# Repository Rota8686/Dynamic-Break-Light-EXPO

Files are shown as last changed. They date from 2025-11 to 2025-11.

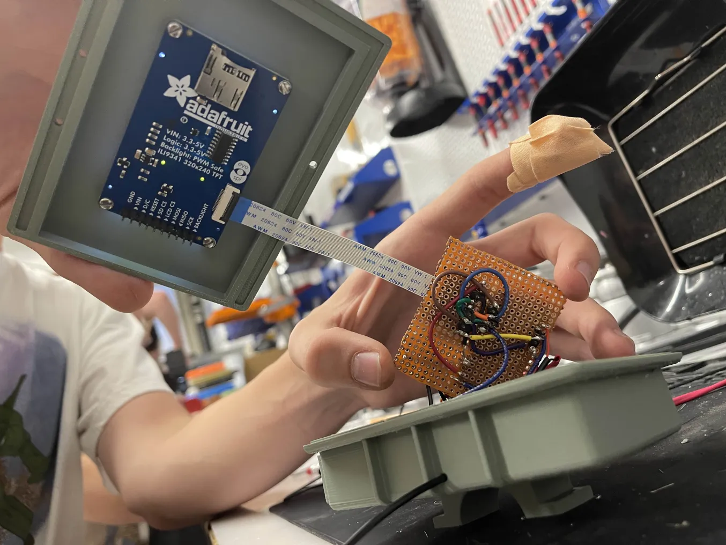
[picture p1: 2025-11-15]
Main Project/Soldering and Assembly/Display Soldering Bottom.webp

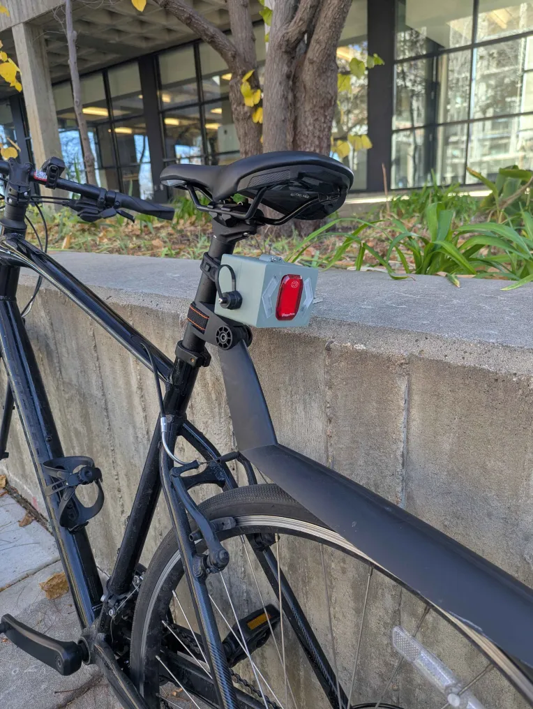
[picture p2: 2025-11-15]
Main Project/Soldering and Assembly/Mounted LED Module Picture.webp

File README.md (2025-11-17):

# Dynamic-Break-Light-EXPO-Repository

This repository holds the final versions of all the files created for the expo prize winning Dynamic Brake Light.

Expo Winning Photo Cropped

Left to Right: Jacob Nguyen, Roman Tagliola, Rowan McCune, Mitchell Vallis, and Liza Gunther (TA)

note: Mitchell Vallis is in Liza Gunther's hands because he had a wedding obligation the day of expo.

# Folder Structure

The "Main Project" folder contains final versions of all the files create for the Dynamic Brake Light, organized into CAD, code, soldering and assembly, presentation materials and technical documents, and expo photos.

The "Team Members" folder holds folders containing each team member's contributions to the Dynamic Brake Light.  These personal folders are organized in a similar manner to the "Main Project" folder, minus an "expo photos" folder.

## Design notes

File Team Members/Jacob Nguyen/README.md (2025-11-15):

## Jacob Nguyen

Jacob Nguyen was a core part of the Dynamic Brake Light team.  Jacob put substantial time and effort into designing the housing for the LED module, developing his soldering skills and diligently preparing useful technical documents and presentation materials.  

Jacob's most significant contribution to the Dynamic Brake Light was his LED module housing.  Going into the project with little CAD experience, Jacob developed a great command over the SolidWorks tools, using them to design a well-thought-out housing.  Jacob balanced visual appeal with clearly identifiable brake and turn signal lights.  To this end, Jacob worked closely with Mitchell Vallis and Rowan McCune to add turn signal cutouts and integrate parts from a commercially available bike light into the LED module housing.

With regard to the implementation of turn signals, Jacob design a geometry for snuggly nesting a single LED bulb flush in the housing.  Jacob developed this geometry through a careful process of trial and error, ultimately resulting in turn signal LED arrays, paired with sanded acrylic cutouts, visible in daylight from any practical angle.  Jacob learned how to operate the laser cutters in the ITLL, where he designed and cut acrylic that held a snug tolerance with the cutouts on the housing.  

During the assembly of the demo version of the Dynamic Brake Light, Jacob dealt with the difficult task of soldering within a compact casing.  From this experience, Jacob greatly improved his soldering technique, as evident by this clean cable management and solid solder joints.  Jacob provided a necessary hand during final assembly and testing, ensuring that all systems functioned properly the night before expo.

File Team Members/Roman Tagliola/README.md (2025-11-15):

## Roman Tagliola

Roman Tagliola was a critical member of the Dynamic Brake Light team.  Roman's most significant contributions to the project include designing the display module, helping the other team members with design subtleties, ensuring timely procurement of electrical components and hardware, and preparing high quality technical documents and presentation materials.  

 Roman demonstrated his command of Onshape's CAD tools in the design of the display module housing, as shown in mounting of the LCD board to the upper clamshell, the fitment and spacing of the display inputs and access points, and the mating of the upper and lower clamshells.  Roman worked with Rowan McCune to integrate the Hall-Effect sensor system with the display module using a cutout in the display housing to connect the sensor to the micro controller using a QWIIC cable setup.

In addition to designing the display module housing, Roman developed the program for the display's micro controller.  The display's program features three user inputs in the form of a reset button, debug/normal UI switch, and a normal/sleep switch.  Roman was responsible for researching and implementing wireless communication between the display and LED modules, which uses an ESP-NOW Wi-Fi channel to maintain two-way transmission between the modules.

Roman laid out and built the circuit boards within the display housing, with soldering assistance from Mitchell Vallis.  Wiring the connections between the micro controller and the display's wire-to-flex board was particularly challenging given eight wires needed soldering in close proximity.  The wiring for the turn signals, switches and button added further complexity to the main board layout.  

By acting as a sounding board for the rest of the team, Roman contributed to the design and exicution of the rest of the project.  Roman encouraged the implementation of the project's reach goal, the addition of turn signals, by providing a picture of how finished turn signals could look and by being proactive in the addition of turn signal functionality to the display module.  Roman also helped Mitchell research reading filter techniques.  

In order to ensure timely procurement of electrical components and hardware, Roman made multiple trips to pick up part orders from SparkFun and hardware from McGuckin's Hardware, local stores based on Niwot, CO and Boulder, CO respectively.

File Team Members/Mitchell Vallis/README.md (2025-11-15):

# Mitchell Vallis

Mitchell Vallis was a critical part of the Dynamic Brake Light team.  Mitchell's primary contributions include envisioning the idea of a dynamic brake light, coding the LED module's micro controller, designing and assembling the LED module's circuit board, and creating high quality technical documents and presentation materials.  Mitchell also helped with designing a compact housing for the LED module and integrating the LED and display systems

During the development of the Dynamic Brake Light, Mitchell was faced with faulty electrical components, intricate coding challenges, and demanding spatial constraints within the LED module housing.  While successfully solving these problems, Mitchell learned proper soldering techniques and developed code to filter and interpret accelerometer readings with the purpose of dynamically controlling LED arrays.

Mitchell's chief accomplishment was writing the code for the accelerometer circuit.  This code turned raw accelerometer voltage readings into dynamically LED controlled arrays using medium pass filters and PWM gradients.

Mitchell's proactive approach to assisting Jacob Nguyen with designing of the LED module housing involved the disassembly of commercially available bike lights and USB cables.  From these items, Mitchell gathered a central LED array and front and rear housing elements seen on the LED module in addition to flexible USB plugs.  Mitchell's instinct to study and integrate what already works directly led to the improvement of the LED housing.  In less words, in the process of helping Jacob, Mitchell constructed a LED module housing that maintained a low profile while containing a circuit board and three separate LED arrays.  

Mitchell worked with Roman Tagliola to establish wireless communication between the LED and display modules using a two-way ESP-NOW Wi-Fi channel.  This wireless communication transmitted accelerometer readings from the LED module to the display and turn signal inputs from the display to the LED module.  Mitchell was committed to the final assembly of the project, designing the internal layout for the LED module and helping Roman with soldering the display module.

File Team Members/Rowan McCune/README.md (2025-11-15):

## Rowan McCune

Rowan McCune was an integral part of the Dynamic Brake Light team.  Rowan made valuable contributions to the project through designing the Hall-Effect sensor system, becoming proficient in his soldering technique, and preparing intuitive presentation materials.  

Rowan's more impressive contribution to the Dynamic Brake Light was his designing and testing of the Hall-Effect sensor system.  The Hall-Effect sensor reads magnetic fields to track wheel rotations, which are in turn used to calculate distance traveled and current velocity.  Rowan exhibited his CAD skills with a robust pair of housing for the Hall-Effect sensor and the magnet caddy.  Rowan designed an effecting script to read the Hall-Effect sensor, featuring tailored baseline adjustments and optimized operating frequencies.  Rowan used the sensor reading script to help Roman Tagliola integrate the sensor readings into the display module's informative UI.  

Rowan demonstrated his soldering technique during final assembly, where he soldered the turn signal LED arrays onto dual-sided copper plated boards, ensuring minimal wiring in the LED module housing and consistent, robust electrical connections.  

Rowan was tasked with making custom acrylic cutouts to fit the turn signals. To accomplish this task, Rowan determined the best combination for our scenario required the acrylic to be sanded and the tops of the LEDs to be grinded flat.  These two design elements together created effective turn signals that are bright and resemble chevrons.

The logo present on PDR and CDR presentations in addition to the display and LED modules is Rowan's design.  The three circles filled with varying shades of red represent the dynamically controlled LED arrays.  The geometric design is reminiscent of logos such as the NASA insignia and the Star Fleet delta emblem.

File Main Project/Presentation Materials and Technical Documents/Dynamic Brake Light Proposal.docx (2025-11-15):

Dynamic Brake Light

Team Light Brakers

Team 21

Lecture WF 3:35p

Rowan McCune, Jacob Nguyen, Roman Tagliola, Mitchell Vallis

“Emails”

Abstract:

Our project is a dynamic break light that increases in brightness the more you are applying the break. This would be most beneficial in cars, to indicate to the person behind the vehicle how much the person in pressing on the breaks. This could lead to decreased car accidents as people would now be aware when the driver ahead of them is slamming on the breaks. We will be implementing this idea and design on a bicycle.

Project Scope:

Plan A:

Our dynamic break light will increase brightness the harder the user is pressing on the brakes. A lollipop shaped device will be attached to the exterior of the handlebars. The stick portion of the lollipop will face forward and will be a channel with a spring inside. The brake handle will fit into the channel. As the break is pulled, the spring will compress, pushing down on a pressure plate at the base of the spring. The more force applied to the pressure plate, the brighter the break light will light up.

Our goal is to create an original, functioning device. The design of the project will allow us to gain experience in coding, 3D printing, design, installation, and troubleshooting. Project success means the light increases in brightness as we increase pressure on the brake handle.

The project will be split into three sections. Coding, 3D design and printing, and installation and troubleshooting. We will create and code the device ourselves. We will use the laser scanner to scan the handlebars of the bike and use those scans to create the attachment for the handlebars. We will buy the spring, wiring, an Arduino to program, and an LED for the brake light. Other miscellaneous pieces might be required as the project gets underway. The 3D printers and laser scanner within the ITLL will be useful and necessary for this project.

Plan B:

Due to the complexity of Plan A, we have come up with a Plan B that uses an accelerometer. We will use an accelerometer to measure acceleration. If there is negative acceleration, the brake light will light up. The greater the deceleration, the greater the brake light lights up.

Specifications:

Electrical:

Component | Minimum Performance | Maximum Performance | Advertised Performance
Arduino | 3 Months | 5 Years | 2-10 years
Batteries | 20 hours | 200 hours | 120 hours
Light | 5,000 hours | 50,000 hours | 25,000 hours
Pressure Sensor | 200 Hours | 300 Hours | NA
Accelerometer | 200 Hours | 500 Hours

Mechanical:

Component | Minimum Performance | Maximum Performance | Advertised Performance
Wiring | 1 Year | 5 Years | 5 Years
Handle Bar Attachment | 6 months | 2 Years
Spring | 1 Year | 3 Years
Mounting Brackets | 2 Years | 4 Years

Design Elements:

Mechanical:

Electrical:

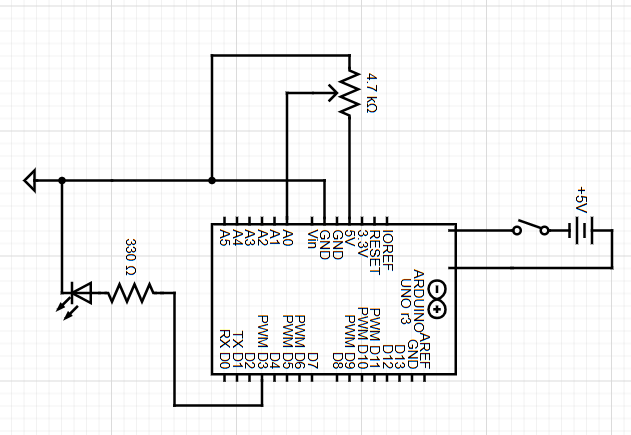
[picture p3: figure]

Bill of Materials:

Item: | Cost ($):
Arduino | $30
Filament for 3D printing | $10
LED | $10
Spring | $3
Wiring | $3
Batteries | $8
Battery Case | $5
On/off Switch | $3
Casing for Arduino | $25
Pressure Sensor | $13
Total: | $110

Risk Mitigation:

The biggest concern is the structural integrity of the Arduino, which we will program to control the LED. Exposure to the elements and vibrations from riding the bike could significantly shorten the life of the Arduino. The mitigate this, we will explore a shock and weather resistant casing.

Timeline:

9/30/25: All parts that need to be ordered are ordered

10/10/25: Designs for 3D printing finalized

10/17/25: Coding Finished

10/31/25: Troubleshooting and testing completed

11/9/25: Finished and installed on bike

Tools:

We will use 3D printers and laser scanners.

Conclusion:

Our plan is attempt Plan A, but due to the complexity and skill restraints, we will quickly shift to Plan B to make sure we have a fully functioning product by the date of the EXPO.

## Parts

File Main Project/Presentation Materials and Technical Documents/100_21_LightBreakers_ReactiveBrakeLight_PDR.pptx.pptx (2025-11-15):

## Light-Braker

Where Safety and Innovation Meet

## Presentation Outline

Idea

Concept

Problem

Timeline

Risk Mitigation

Testing

Summary

Bill of Materials

## Problem

- Most bikes don’t have a brake light to indicate that they are braking
- Congested bike lanes can reduce the rider’s reaction time leading to crashes

Solution

Create a brake light that lets trailing riders know you are braking and how fast

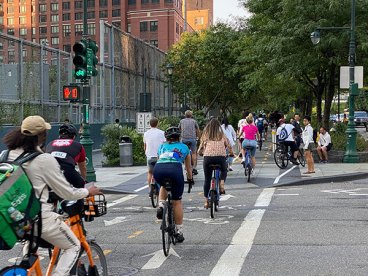
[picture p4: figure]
The BroadsheetDAILY - 10/11/22 - Street Wise - The Broadsheet

## Introducing the Dynamic Brake Light

- Increases in brightness the quicker you are slowing down
- Uses an accelerometer to take acceleration inputs
- As negative acceleration increases, power output to the brake light increases
- Added LCD display and distance tracking

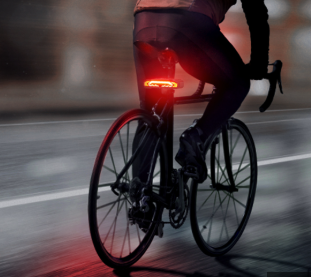
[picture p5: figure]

## Introducing the Dynamic Break Light

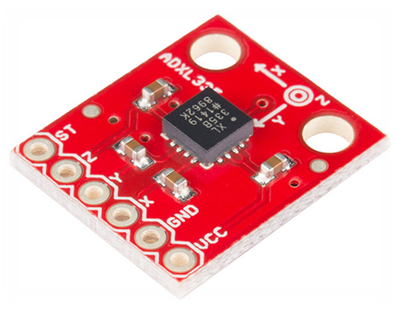
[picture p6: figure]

Accelerometer ADXL335 (https://www.digikey.com/en/htmldatasheets/production/466599/0/0/1/adxl335)

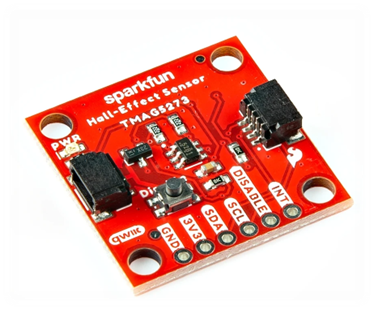
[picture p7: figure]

Hall-Effect Sensor (https://docs.sparkfun.com/SparkFun_Qwiic_Hall_Effect_Sensor_TMAG5273/assets/component_documentation/tmag5273.pdf)

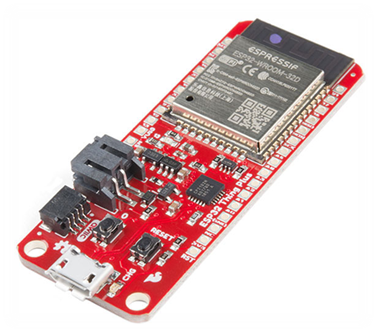
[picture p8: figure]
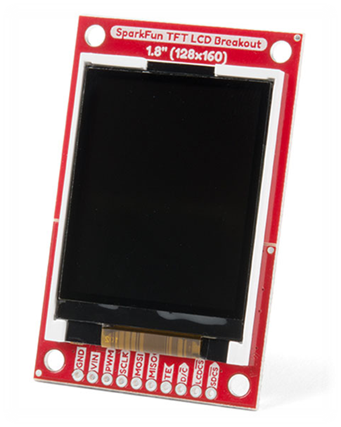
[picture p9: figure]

Thing Plus ESP32 (https://cdn.sparkfun.com/assets/4/3/1/7/6/esp32-wroom-32e_esp32-wroom-32ue_datasheet_en_v1-6.pdf)

TFT LCD Breakout (https://cdn.sparkfun.com/assets/9/0/4/1/e/KWH018ST14-F01_B_20181212.pdf)

## Electronics

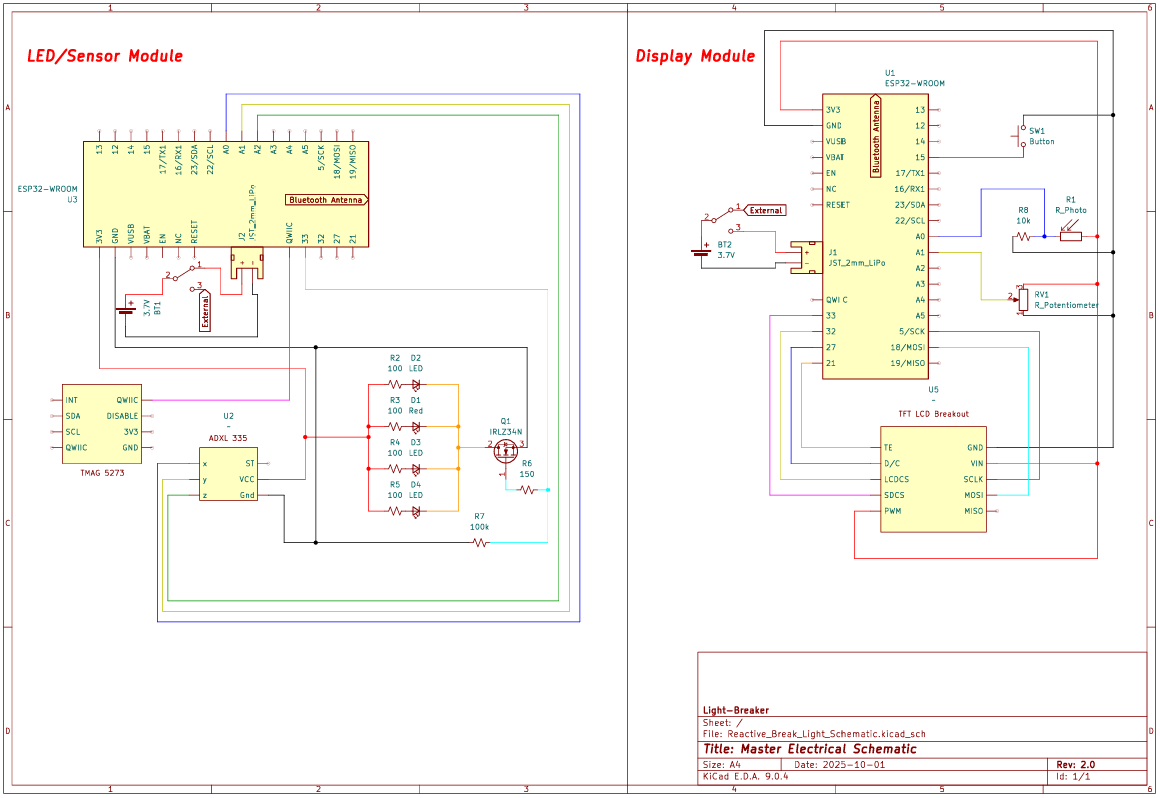
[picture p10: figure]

Why the ESP32 platform over the UNO?
- Size
- Processing Power
- Bluetooth and Wi-fi Integration
TFT LCD Breakout
- similar to the TI-84 PLUS CE display
- customizable interface
- SparkFun HyperDisplay library
Sensors provide analog readings, creating room for fine tuning.

## Code

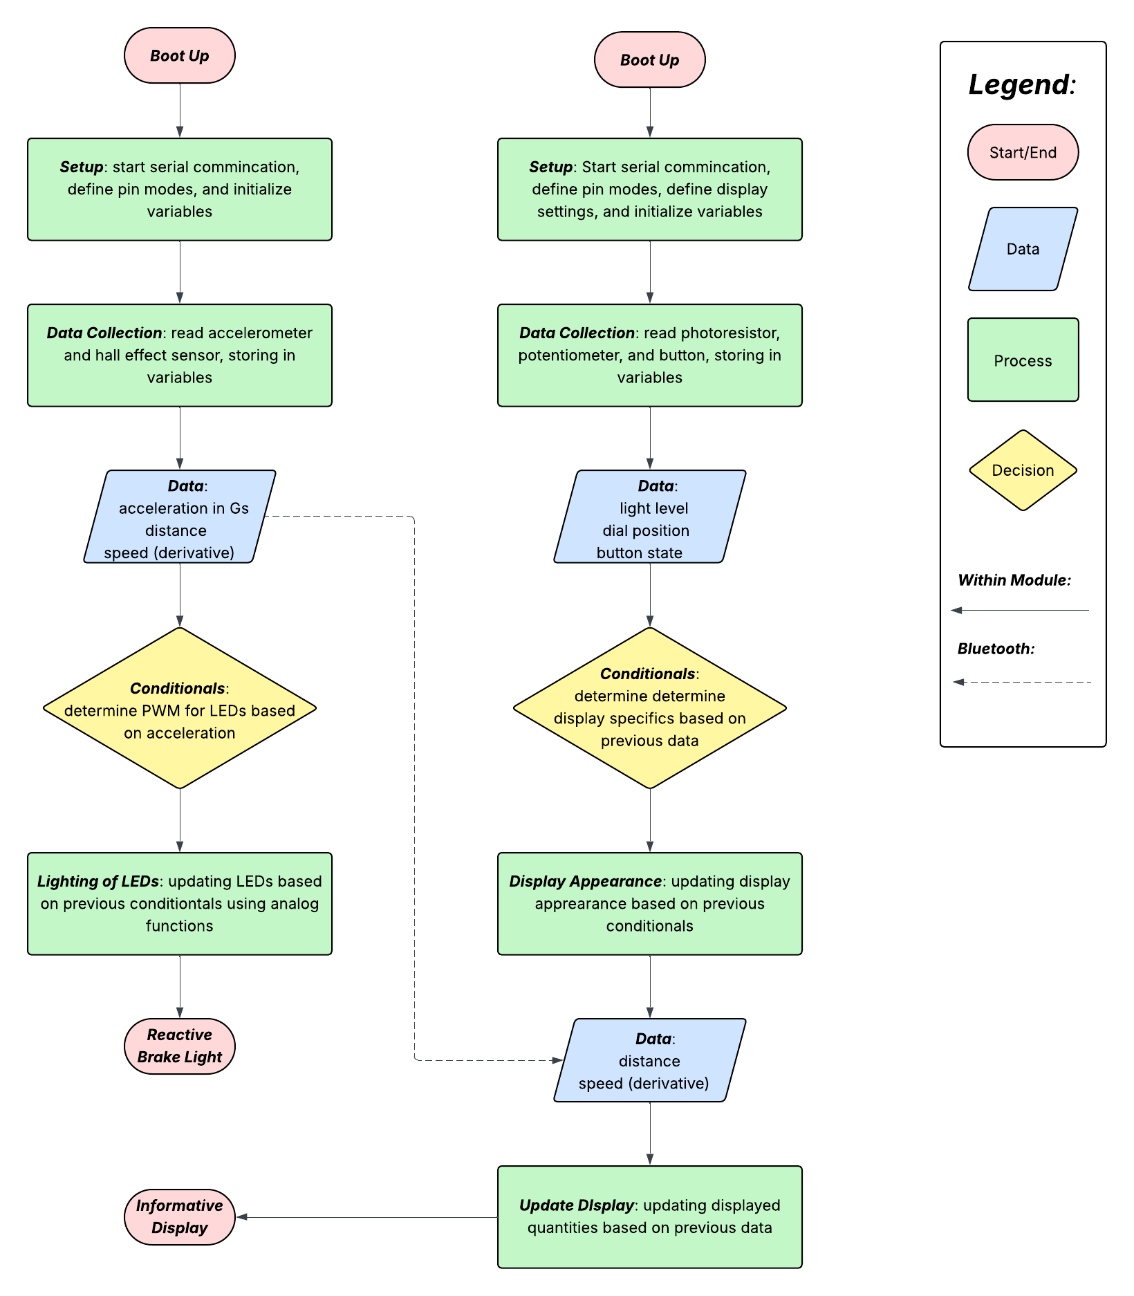
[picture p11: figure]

Arduino IDE
- easy to learn
- good user interface
- variety of documented libraries
  - Espressif esp32 library
  - SparkFun HyperDisplay library
  - ArduinoBLE library

Issues:
- esp32 specific analog functions
  - ledcWrite() alternative to analogWrite()
- 3.x.x verions of Espressif esp32 library broke the defining of ledc functions

## Electrical Enclosures


Software:
- Onshape (Cloud)
- PrusaSlicer

3D Printing:
- Prototyping: PLA
- Expo: Nylon Filament


## Timeline


Responsibilities:
- each teammate responsible for one area of the project
  - Mitchell: accelerometer
  - Jacob: LED array
  - Rowan: tachometer
  - Roman: LCD display

Jira:
- used to keep track of tasks, expenses, and deadlines
- Gantt Chart

## Testing Plan

Integration and Design:
- be resourceful.
- use amenities provided to us
- Craft a brand through seamless design. This is an expo!

Think Traffic - Philly Ad Club

Hardware:
- Ensuring that microcontrollers integrate well with our system
- LCD Screen
- Accelerometer
- Hall Effect Sensor
- Bluetooth Communication
- Batteries
- Test components on a breadboard. Spend time doing the MATH!

Solderless Breadboard 400 pins

Software:
- capable of supporting the hardware
  - ensuring everyone is on the same page
  - testing code before soldering

Free download | HD PNG arduino logo PNG transparent with Clear Background ID 222719 | TOPpng

## Risk Mitigation

Potential Risk | Our Plan
Not having enough power | To use an external supply that goes into the Arduino Board
Wires and connection coming loose due to bumps and shaking of the bicycle | Create absorbent casings that minimize the bumps, maintaining a strong connection and solder our parts.
Errors in coding when it comes to the luminosity of the lights, LCD Display, Accelerometer, and Hall-Effect Sensor | Preprogram all our components on a breadboard before attaching it to the bike, and using trial and error to resolve any errors

## Bill of Materials

Item Name | Price (USD) | Where? | Importance
SparkFun Triple Axis Accelerometer Breakout | 19.50 | Amazon | Measures our acceleration, allowing us to know when we are slowing down.
SparkFun Linear 3D Hall-Effect Sensor | 7.11 | Amazon | Magnetic field sensor to determine the distance travelled on the bike
LED – Super Bright Red (25 Pack) | 4.75 | SparkFun Electronics | Makes up or brake light on the back of the bike
SparkFun Qwiic Cable Kit | 12.95 | SparkFun Electronics | Allows us to wire things faster with less error
SparkFun Capacitor Kit | 11.50 | SparkFun Electronics | Allows us to more precisely control the thresholds
SparkFun TFT LCD Breakout – 1.8" (128x160) | 34.95 | SparkFun Electronics | This is our digital display for our speed, distance, etc.
2x SparkFun Thing Plus – ESP32 WROOM (Micro-B) | 24.95 per 49.90 total | SparkFun Electronics | These are the core of our circuit and project

## Summary

- We've identified an issue and have developed a solution
- Our dynamic brake light is intended to reduce bike accidents
- Through our planned testing and navigating risks our device will be optimized
Questions?

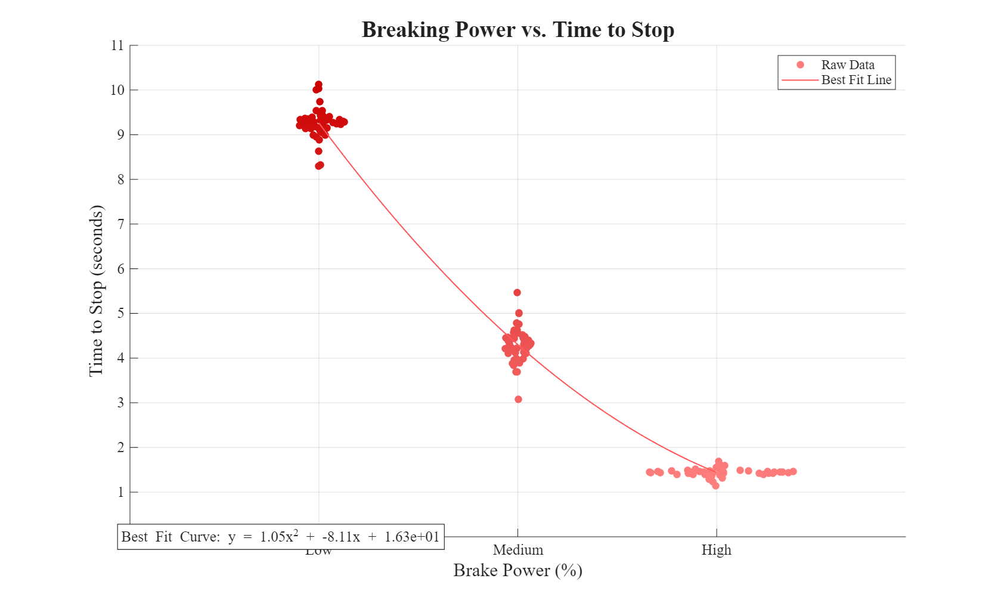
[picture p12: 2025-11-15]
Main Project/Presentation Materials and Technical Documents/MATLAB Graphs/bp_vs_tts.png

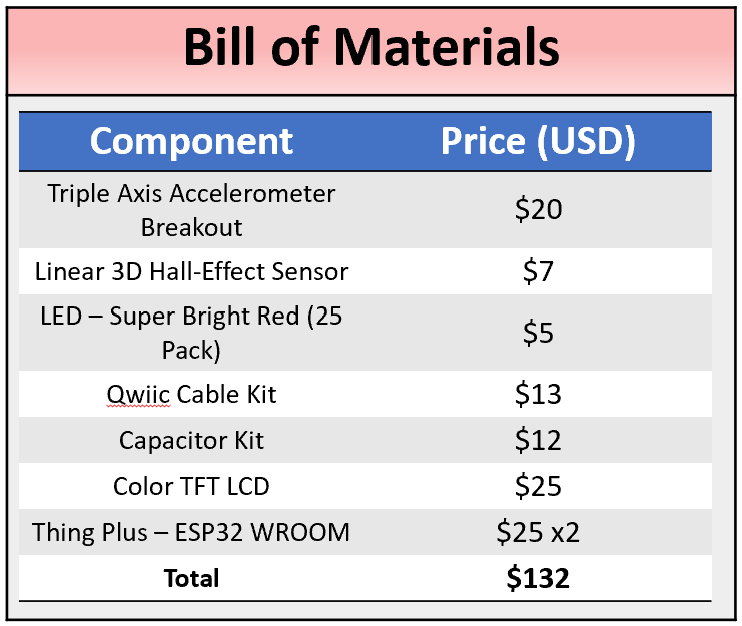
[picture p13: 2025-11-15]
Main Project/Presentation Materials and Technical Documents/Bill of Materials.png

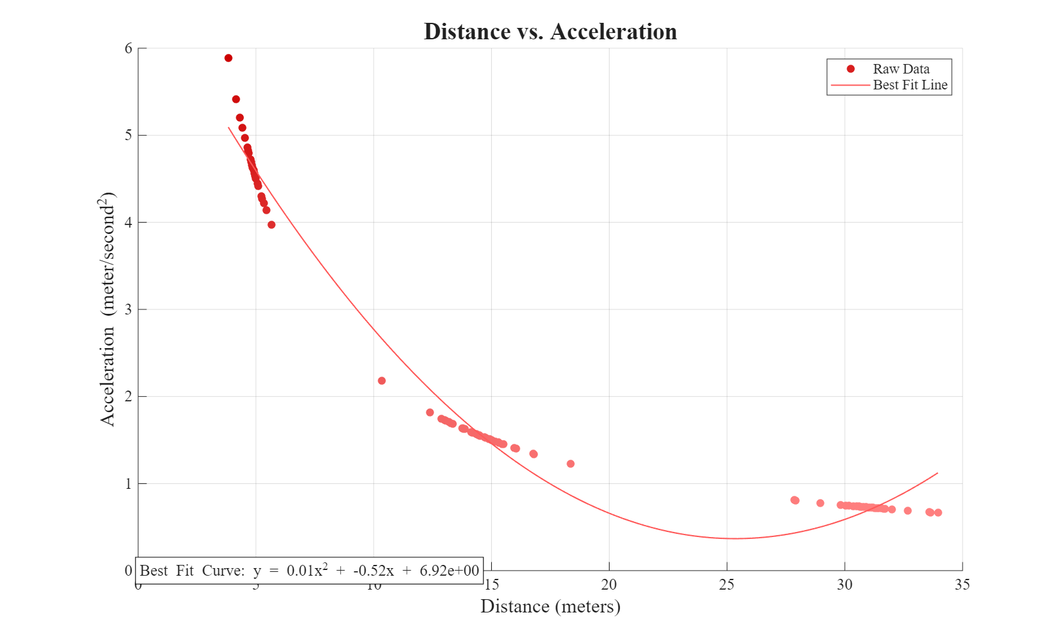
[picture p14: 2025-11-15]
Main Project/Presentation Materials and Technical Documents/MATLAB Graphs/a_vs_d.png

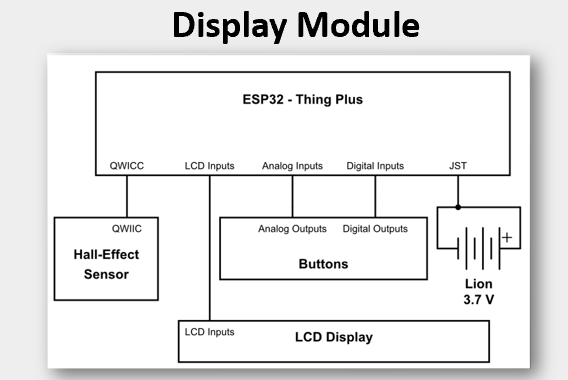
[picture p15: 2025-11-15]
Main Project/Presentation Materials and Technical Documents/Final Display Block Diagram.png

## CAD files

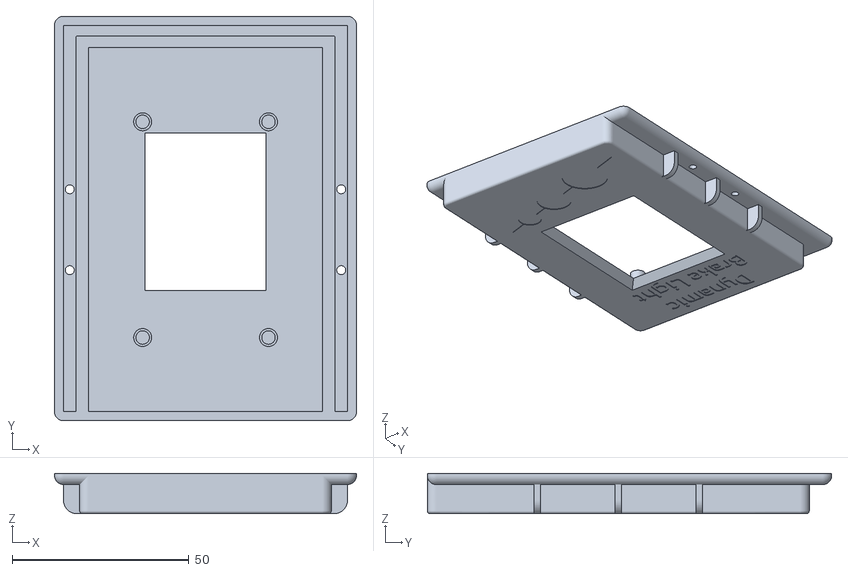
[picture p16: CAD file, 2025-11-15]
Main Project/CAD/Display Upper Clamshell V3.2.stl
85.3 x 114.3 x 11.4

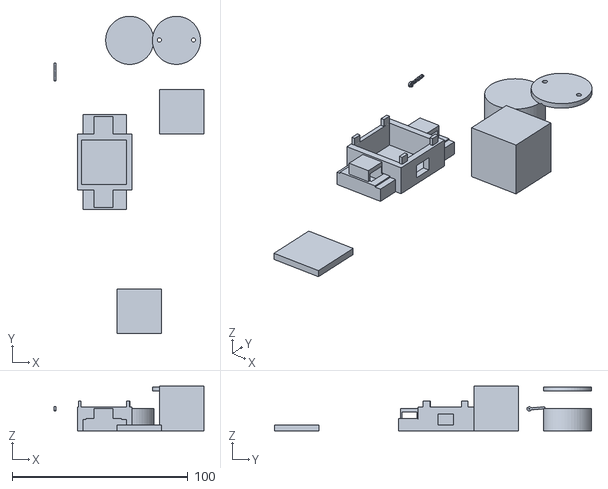
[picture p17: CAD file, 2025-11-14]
Team Members/Rowan McCune/CAD/Hall-Effect Sensor System CAD.stl
85.3 x 180.6 x 25.4

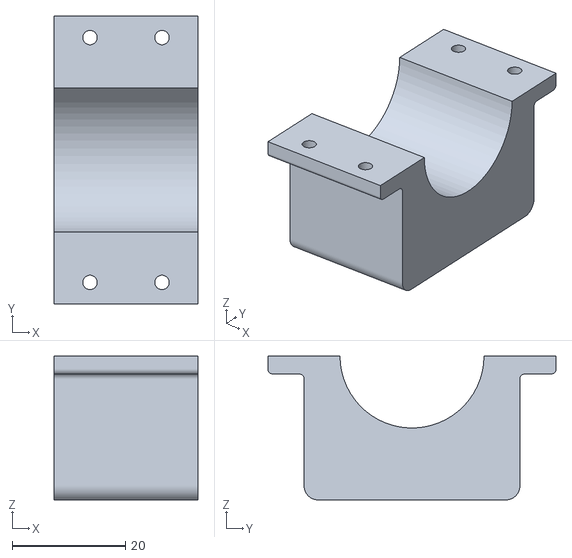
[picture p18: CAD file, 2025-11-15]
Main Project/CAD/Exterior Clamp V3.stl
25.4 x 50.8 x 25.4

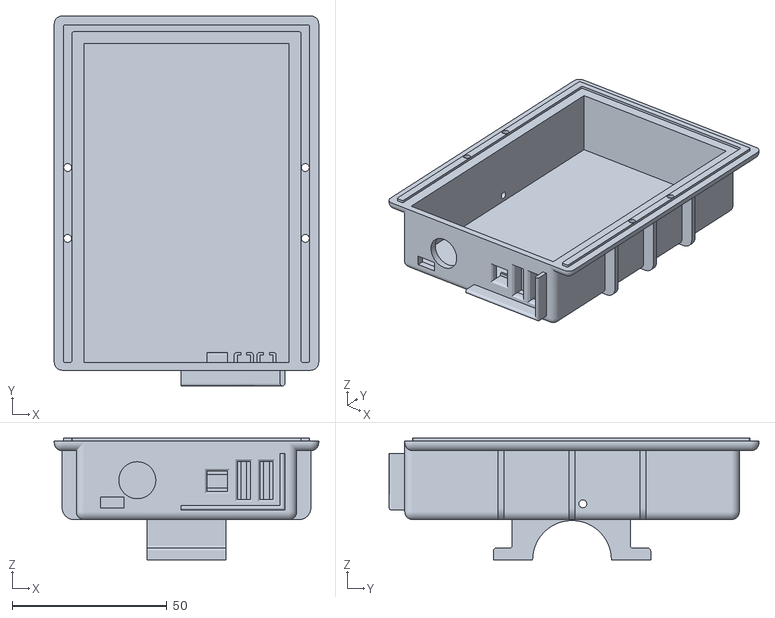
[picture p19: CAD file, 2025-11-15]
Main Project/CAD/Display Lower Clamshell V3.1.stl
85.3 x 119.4 x 39.3

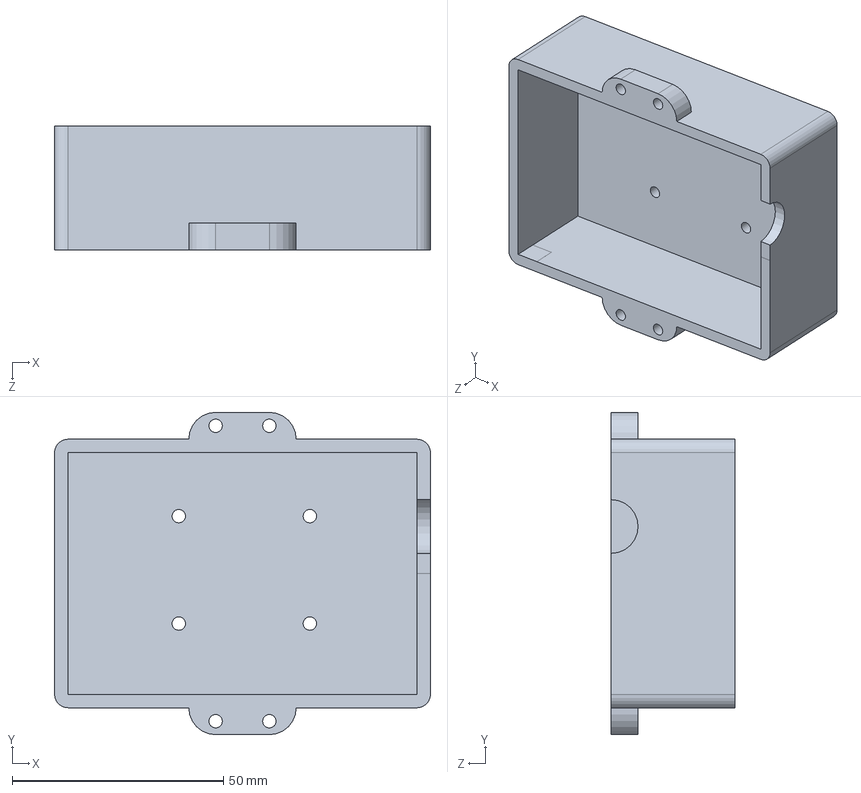
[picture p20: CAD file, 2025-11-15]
Main Project/CAD/Back Casing With Signals 2.SLDPRT
88.9 x 76.2 x 29.2 mm

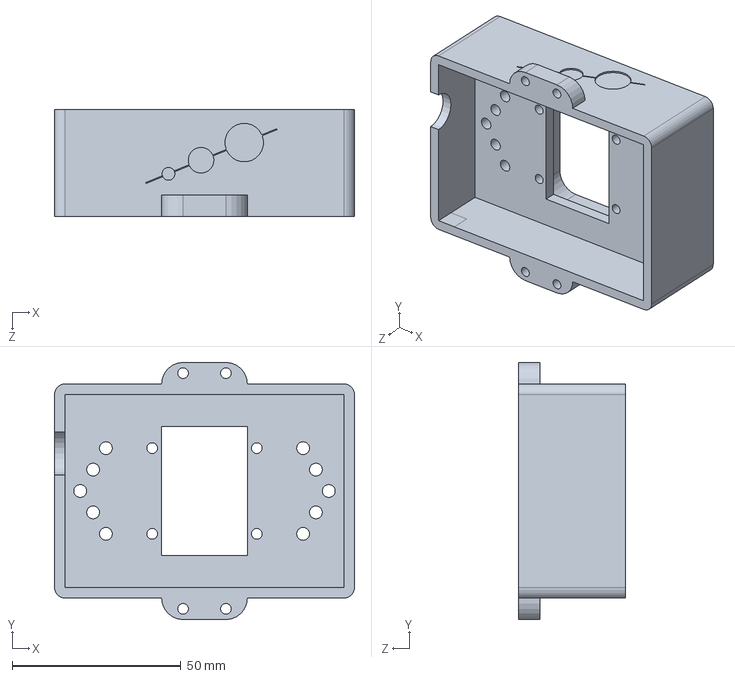
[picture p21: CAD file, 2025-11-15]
Main Project/CAD/Front Casing With Signals 5.SLDPRT
88.9 x 76.2 x 31.8 mm

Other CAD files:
Main Project/CAD/LED Glass Cut Out Shape.SLDPRT
Main Project/CAD/Back Casing With Signals 2.STL
Main Project/CAD/Front Casing With Signals 5.STL
Main Project/CAD/LED Glass Cut Out Shape.DXF

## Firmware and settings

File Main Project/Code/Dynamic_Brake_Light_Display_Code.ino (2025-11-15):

#include <TFT_eSPI.h>
#include <esp_now.h>
#include <WiFi.h>
#include <Wire.h>
#include <SparkFun_TMAG5273_Arduino_Library.h>

//I2C configuration
#define SDA_PIN 23
#define SCL_PIN 22

//control inputs 
#define POWER_SWITCH_PIN 32
#define MODE_SWITCH_PIN 4
#define RESET_BUTTON_PIN 0
#define SIGNAL_A_PIN 27
#define SIGNAL_B_PIN 14

//Hall-Effect sensor calibration
float Z_baseline = -0.68;
float Z_high = 1.0;
float Z_low = 0.3;

//wheel configuration
#define WHEEL_DIAMETER_CM 66.0
#define WHEEL_CIRCUMFERENCE_CM (WHEEL_DIAMETER_CM * 3.14159)
#define WHEEL_CIRCUMFERENCE_M (WHEEL_CIRCUMFERENCE_CM / 100.0)
#define WHEEL_CIRCUMFERENCE_INCHES (WHEEL_CIRCUMFERENCE_CM / 2.54)

//constants for conversion
const float INCHES_PER_MILE = 63360.0;
const float METERS_PER_KM = 1000.0;
const int MAG_SAMPLES = 5;
const unsigned long VELOCITY_TIMEOUT_MS = 3000;

//data structure for receiving from sender
typedef struct struct_message_in {
  float accelValue;
  unsigned long timestamp;
} struct_message_in;

//data structure for sending to sender
typedef struct struct_message_out {
  bool buttonA;
  bool buttonB;
  unsigned long timestamp;
} struct_message_out;

struct_message_in incomingData;
struct_message_out outgoingData;

//sender MAC address
uint8_t senderAddress[] = {0xFF, 0xFF, 0xFF, 0xFF, 0xFF, 0xFF};

//assigning variables
TFT_eSPI tft = TFT_eSPI();
TMAG5273 hallSensor;
esp_now_peer_info_t peerInfo;

float accelValue = 0.0;
float velocity_mps = 0.0; 
float velocity_kmh = 0.0;
float velocity_mph = 0.0;
float hallFieldStrength = 0.0;
float magZ_averaged = 0.0;
unsigned long lastPulseTime = 0;
unsigned long pulseInterval = 0;
unsigned long pulseCount = 0;
unsigned long lastDataReceived = 0;
unsigned long packetsReceived = 0;
float totalDistanceMiles = 0.0;
float totalDistanceKm = 0.0;
bool receivedData = false;
bool magnetDetected = false;
bool lastMagnetState = false;

//control variables
bool powerOn = false;
bool lastPowerState = false;
bool debugMode = false;
bool lastDebugMode = false;
bool signalA = false;
bool signalB = false;
bool lastSignalA = false;
bool lastSignalB = false;

//callback when data is received
void OnDataRecv(const uint8_t *mac, const uint8_t *incomingDataPtr, int len) {
  memcpy(&incomingData, incomingDataPtr, sizeof(incomingData));
  accelValue = incomingData.accelValue;
  lastDataReceived = millis();
  receivedData = true;
  packetsReceived++;
}

//callback when data is sent
void OnDataSent(const uint8_t *mac_addr, esp_now_send_status_t status) {
  if (status != ESP_NOW_SEND_SUCCESS) {
    Serial.println("button signal send failed");
  }
}

void setup() {
  Serial.begin(115200);
  delay(1000);
  Serial.println("\n\nESP32 receiver - wireless display with TMAG5273");

  //initialize control inputs
  pinMode(POWER_SWITCH_PIN, INPUT_PULLUP);
  pinMode(MODE_SWITCH_PIN, INPUT_PULLUP);
  pinMode(SIGNAL_A_PIN, INPUT_PULLUP);
  pinMode(SIGNAL_B_PIN, INPUT_PULLUP);
  
  Serial.println("controls initialized");

  //start I2C 
  Wire.begin(SDA_PIN, SCL_PIN);
  Wire.setClock(400000);

  //start Hall-Effect sensor
  if (hallSensor.begin(TMAG5273_I2C_ADDRESS_INITIAL, Wire) == 1) {
    Serial.println("TMAG5273 Hall-Effect sensor connected");
    Serial.print("baseline Z: ");
    Serial.print(Z_baseline, 3);
    Serial.print(" | high threshold: ");
    Serial.print(Z_high, 3);
    Serial.print(" | low threshold: ");
    Serial.println(Z_low, 3);
    Serial.print("wheel circumference: ");
    Serial.print(WHEEL_CIRCUMFERENCE_M, 3);
    Serial.print(" m (");
    Serial.print(WHEEL_CIRCUMFERENCE_INCHES, 2);
    Serial.println(" inches)");
  } else {
    Serial.println("error: TMAG5273 sensor not detected");
  }

  //set this controller as a WiFi station
  WiFi.mode(WIFI_STA);

  //print MAC address
  Serial.print("receiver MAC address: ");
  Serial.println(WiFi.macAddress());
  Serial.println("COPY THIS ADDRESS TO SENDER CODE!");

  //initialize ESP-NOW
  if (esp_now_init() != ESP_OK) {
    Serial.println("error initializing ESP-NOW");
    return;
  }

  //register receive callback
  esp_now_register_recv_cb(OnDataRecv);
  
  //register send callback
  esp_now_register_send_cb(OnDataSent);
  
  //register peer
  memcpy(peerInfo.peer_addr, senderAddress, 6);
  peerInfo.channel = 0;  
  peerInfo.encrypt = false;
  
  if (esp_now_add_peer(&peerInfo) != ESP_OK) {
    Serial.println("failed to add peer");
  }

  //start TFT display
  tft.init();
  tft.setRotation(0);
  tft.fillScreen(TFT_BLACK);
  tft.setTextColor(TFT_WHITE, TFT_BLACK);

  //initial screen
  drawWelcomeScreen();

  Serial.println("system started");
  Serial.println("\n=== CONTROLS ===");
  Serial.println("power switch: toggle system on/off");
  Serial.println("mode switch: toggle debug/normal mode");
  Serial.println("reset button: hardware reset (connected to EN pin)");
  Serial.println("signal A button: send signal A via ESP-NOW");
  Serial.println("signal B button: send signal B via ESP-NOW");
}

void loop() {

  //read control inputs
  readControls();
  
  //check power state
  if (!powerOn) {
    if (lastPowerState) {
      showSleepScreen();
    }
    lastPowerState = powerOn;
    delay(100);
    return;
  }
  
  //system is on
  if (!lastPowerState) {
    tft.fillScreen(TFT_BLACK);
    if (debugMode) {
      drawDebugLabels();
    } else {
      drawNormalLabels();
    }
  }
  lastPowerState = powerOn;

  //check for data timeout
  if (millis() - lastDataReceived > 2000 && receivedData) {
    receivedData = false;
    Serial.println("data timeout - no signal from sender");
  }

  //read Hall-Effect sensor
  readHallSensor();

  //calculate velocity
  calculateVelocity();

  //update the display based on mode
  if (debugMode) {
    updateDebugDisplay();
  } else {
    updateNormalDisplay();
  }

  //debug output
  static unsigned long lastDebugPrint = 0;
  if (millis() - lastDebugPrint > 2000 && debugMode) {
    Serial.print("Z: ");
    Serial.print(magZ_averaged, 3);
    Serial.print(" | Δ: ");
    Serial.print(magZ_averaged - Z_baseline, 3);
    Serial.print(" | passes: ");
    Serial.print(pulseCount);
    Serial.print(" | distance: ");
    Serial.print(totalDistanceMiles, 6);
    Serial.print(" mi (");
    Serial.print(totalDistanceKm, 3);
    Serial.print(" km) | speed: ");
    Serial.print(velocity_kmh, 1);
    Serial.println(" km/h");
    lastDebugPrint = millis();
  }

  delay(20);
}

//defining local functions

void readControls() {
  
  //read switches and buttons
  powerOn = !digitalRead(POWER_SWITCH_PIN);
  bool currentDebugMode = !digitalRead(MODE_SWITCH_PIN);
  signalA = !digitalRead(SIGNAL_A_PIN);
  signalB = !digitalRead(SIGNAL_B_PIN);
  
  //check for mode switch change
  if (currentDebugMode != lastDebugMode) {
    debugMode = currentDebugMode;
    Serial.print("mode switched to: ");
    Serial.println(debugMode ? "DEBUG" : "NORMAL");
    tft.fillScreen(TFT_BLACK);
    if (debugMode) {
      drawDebugLabels();
    } else {
      drawNormalLabels();
    }
  }
  lastDebugMode = currentDebugMode;
  
  //check for button presses and send via ESP-NOW
  if ((signalA && !lastSignalA) || (signalB && !lastSignalB)) {
    sendButtonSignals();
  }
  
  lastSignalA = signalA;
  lastSignalB = signalB;
}

void sendButtonSignals() {
  outgoingData.buttonA = signalA;
  outgoingData.buttonB = signalB;
  outgoingData.timestamp = millis();
  
  esp_err_t result = esp_now_send(senderAddress, (uint8_t *) &outgoingData, sizeof(outgoingData));
  
  if (result == ESP_OK) {
    Serial.print("button signal sent - A: ");
    Serial.print(signalA ? "ON" : "OFF");
    Serial.print(" B: ");
    Serial.println(signalB ? "ON" : "OFF");
  } else {
    Serial.println("error sending button signal");
  }
}

void readHallSensor() {
  
  //averaging for smoother readings
  float sum = 0;
  for (int i = 0; i < MAG_SAMPLES; i++) {
    sum += hallSensor.getZData();
    delayMicroseconds(100);
  }
  magZ_averaged = sum / MAG_SAMPLES;
  
  //calculate field strength
  hallFieldStrength = abs(magZ_averaged - Z_baseline);
  
  //magnet detection
  float delta = magZ_averaged - Z_baseline;
  
  if (delta > Z_high && !magnetDetected) {
    unsigned long currentTime = micros();
    
    if (currentTime - lastPulseTime > 100000) {
      pulseInterval = currentTime - lastPulseTime;
      lastPulseTime = currentTime;
      pulseCount++;
      magnetDetected = true;
      
      //calculate cumulative distance
      float distanceInches = pulseCount * WHEEL_CIRCUMFERENCE_INCHES;
      totalDistanceMiles = distanceInches / INCHES_PER_MILE;
      totalDistanceKm = (pulseCount * WHEEL_CIRCUMFERENCE_M) / METERS_PER_KM;
      
      Serial.print(">>> MAGNET DETECTED! Revolution ");
      Serial.print(pulseCount);
      Serial.print(" | delta: ");
      Serial.print(delta, 3);
      Serial.print(" | distance: ");
      Serial.print(totalDistanceKm, 3);
      Serial.println(" km");
    }
  } 
  else if (delta < Z_low && magnetDetected) {
    magnetDetected = false;
  }
  
  lastMagnetState = magnetDetected;
}

void calculateVelocity() {
  if (pulseCount == 0 || lastPulseTime == 0) {
    velocity_mps = 0.0;
    velocity_kmh = 0.0;
    velocity_mph = 0.0;
    return;
  }

  unsigned long timeSinceLastPulse = millis() - (lastPulseTime / 1000);
  if (timeSinceLastPulse > VELOCITY_TIMEOUT_MS) {
    velocity_mps = 0.0;
    velocity_kmh = 0.0;
    velocity_mph = 0.0;
    return;
  }

  if (pulseInterval > 0) {
    float timePerRev = pulseInterval / 1000000.0;

    velocity_mps = WHEEL_CIRCUMFERENCE_M / timePerRev;
    velocity_kmh = velocity_mps * 3.6;
    velocity_mph = velocity_kmh * 0.621371;

    if (velocity_kmh > 60.0) {
      Serial.println("WARNING: Unrealistic speed detected, zeroing velocity");
      velocity_kmh = 0.0;
      velocity_mps = 0.0;
      velocity_mph = 0.0;
    }
  }
}

void drawWelcomeScreen() {
  tft.fillScreen(TFT_BLACK);
  tft.setTextSize(2);
  tft.setTextColor(TFT_RED, TFT_BLACK);
  tft.setCursor(30, 100);
  tft.print("BIKE COMPUTER");
  tft.setTextSize(1);
  tft.setTextColor(TFT_WHITE, TFT_BLACK);
  tft.setCursor(20, 130);
  tft.print("Toggle power switch");
  tft.setCursor(40, 145);
  tft.print("to start system");
}

void showSleepScreen() {
  tft.fillScreen(TFT_BLACK);
  tft.setTextSize(2);
  tft.setTextColor(TFT_DARKGREY, TFT_BLACK);
  tft.setCursor(60, 150);
  tft.print("SLEEP");
}

void drawDebugLabels() {
  tft.setTextSize(2);
  tft.setTextColor(TFT_RED, TFT_BLACK);
  
  tft.setCursor(10, 10);
  tft.print("ACCEL:");
  
  tft.setCursor(10, 40);
  tft.print("HALL:");
  
  tft.setCursor(10, 70);
  tft.print("SPEED:");
  
  tft.setCursor(10, 110);
  tft.print("DISTANCE:");
  
  tft.setCursor(10, 160);
  tft.print("PULSES:");
  
  tft.setCursor(10, 190);
  tft.print("PACKETS:");
  
  tft.setCursor(10, 220);
  tft.print("WIFI:");
  
  tft.setCursor(10, 250);
  tft.print("SIGNALS:");
}

void drawNormalLabels() {
  tft.setTextSize(2);
  tft.setTextColor(TFT_RED, TFT_BLACK);
  
  tft.setCursor(10, 10);
  tft.print("SPEED:");
  
  tft.setCursor(10, 100);
  tft.print("DISTANCE:");
  
  tft.setCursor(10, 145);
  tft.print("ACCELERATION:");
}

void updateDebugDisplay() {
  
  //display accelerometer data
  tft.setTextSize(2);
  tft.setTextColor(TFT_YELLOW, TFT_BLACK);
  tft.setCursor(120, 10);
  if (receivedData) {
    tft.print(accelValue, 2);
    tft.print("    ");
  } else {
    tft.setTextColor(TFT_RED, TFT_BLACK);
    tft.print("--  ");
  }

  //display Hall-Effect field strength
  tft.setTextColor(TFT_MAGENTA, TFT_BLACK);
  tft.setCursor(120, 40);
  tft.print(hallFieldStrength, 2);
  if (magnetDetected) {
    tft.print("*");
  } else {
    tft.print(" ");
  }
  tft.print("   ");

  //display speed
  tft.setTextColor(TFT_GREEN, TFT_BLACK);
  tft.setCursor(120, 70);
  tft.print(velocity_kmh, 1);
  tft.print("    ");

  //display distance
  tft.setTextColor(TFT_RED, TFT_BLACK);  
  tft.setCursor(10, 130);
  tft.print(totalDistanceMiles, 3);
  tft.print(" mi   ");

  //display pulses
  tft.setTextColor(TFT_WHITE, TFT_BLACK);
  tft.setCursor(120, 160);
  tft.print(pulseCount);
  tft.print("     ");
  
  //display packets
  tft.setCursor(120, 190);
  tft.print(packetsReceived);
  tft.print("     ");

  //display WiFi status
  tft.setCursor(80, 220);
  if (receivedData) {
    tft.setTextColor(TFT_GREEN, TFT_BLACK);
    tft.print("OK ");
  } else {
    tft.setTextColor(TFT_RED, TFT_BLACK);
    tft.print("-- ");
  }
  
  //display button signals
  tft.setTextColor(TFT_WHITE, TFT_BLACK);
  tft.setCursor(130, 250);
  tft.print("A:");
  tft.print(signalA ? "1" : "0");
  tft.print(" B:");
  tft.print(signalB ? "1" : "0");
  tft.print("  ");
}

void updateNormalDisplay() {
  
  //display speed
  tft.setTextSize(4);
  tft.setTextColor(TFT_GREEN, TFT_BLACK);
  tft.setCursor(20, 40);
  if (velocity_mph >= 100.0) {
    tft.print((int)velocity_mph);
  } else if (velocity_mph >= 10.0) {
    tft.print(" ");
    tft.print((int)velocity_mph);
  } else {
    tft.print("  ");
    tft.print((int)velocity_mph);
  }
  tft.setTextSize(2);
  tft.print(" mph  ");

  //display distance
  tft.setTextSize(2);
  tft.setTextColor(TFT_WHITE, TFT_BLACK);  
  tft.setCursor(20, 120);
  tft.print(totalDistanceMiles, 2);
  tft.print(" mi  ");
  
  //draw acceleration circle
  drawAccelerationCircle();
  
  //show connection status
  tft.setTextSize(1);
  tft.setCursor(10, 290);
  if (receivedData) {
    tft.setTextColor(TFT_GREEN, TFT_BLACK);
    tft.print("CONNECTED");
  } else {
    tft.setTextColor(TFT_RED, TFT_BLACK);
    tft.print("NO SIGNAL");
  }
  tft.print("     ");
}

void drawAccelerationCircle() {
  float accel = abs(accelValue);
  int mappedValue = constrain(accel, 0, 3000);
  int radius = map(mappedValue, 0, 3000, 5, 65);
  
  int centerX = 120;
  int centerY = 225;
  
  static int lastRadius = 5;
  
  int radiusDiff = abs(radius - lastRadius);
  if (radiusDiff > 1) {
    
    if (lastRadius > 0) {
      tft.fillCircle(centerX, centerY, lastRadius + 2, TFT_BLACK);
    }
    
    tft.fillCircle(centerX, centerY, radius, TFT_RED);
    tft.drawCircle(centerX, centerY, radius + 1, TFT_WHITE);
    
    lastRadius = radius;
  }
  
  static float lastAccel = 0;
  if (abs(accel - lastAccel) > 50) {
    tft.fillRect(centerX - 20, centerY - 6, 40, 12, TFT_RED);
    
    tft.setTextSize(1);
    tft.setTextColor(TFT_WHITE, TFT_RED);
    tft.setCursor(centerX - 15, centerY - 4);
    tft.print(accel, 0);
    
    lastAccel = accel;
  }
}

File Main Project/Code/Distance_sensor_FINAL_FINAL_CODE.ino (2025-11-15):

#include <Wire.h>
#include "SparkFun_TMAG5273_Arduino_Library.h"

TMAG5273 sensor;

void setup() {
  Wire.begin();
  Serial.begin(500000); // Increased baud rate

  if (sensor.begin(TMAG5273_I2C_ADDRESS_INITIAL, Wire) != 1) {
    Serial.println("❌ Sensor failed to initialize");
    while (1);
  }

  Serial.println("✅ Hall Sensor Distance Tracker (Miles Version, 500000 baud)");
}

void loop() {
  static bool magnetDetected = false;
  static unsigned long passCount = 0;
  static unsigned long lastTime = 0;

  // ---- IMPERM VALS ----
  float Z_baseline = -0.68;   // Baseline reading without magnet
  float Z_high = 1.0;         // IMPERM VAL — Trigger threshold
  float Z_low  = 0.3;         // IMPERM VAL — Reset threshold
  float revDistance = 86.393; // Inches per revolution (IMPERM VAL)
  const float INCHES_PER_MILE = 63360.0;

  // ---- Averaging for smoother readings ----
  const int samples = 5;
  float sum = 0;
  for (int i = 0; i < samples; i++) {
    sum += sensor.getZData();
    delay(1); // minimal delay for I2C stability
  }
  float magZ = sum / samples;

  // ---- Debug output ----
  Serial.print("Z = ");
  Serial.print(magZ, 3);
  Serial.print(" | Δ = ");
  Serial.print(magZ - Z_baseline, 3);

  // ---- Magnet detection ----
  if ((magZ - Z_baseline) > Z_high && !magnetDetected) {
    passCount++;
    magnetDetected = true;
    Serial.print("  >>> 🧲 MAGNET DETECTED! (Pass ");
    Serial.print(passCount);
    Serial.println(")");
  } 
  else if ((magZ - Z_baseline) < Z_low && magnetDetected) {
    magnetDetected = false;
    Serial.println();
  } 
  else {
    Serial.println();
  }

  // ---- Print distance every second ----
  unsigned long currentTime = millis();
  if (currentTime - lastTime >= 1000) {
    float distanceInches = passCount * revDistance;
    float distanceMiles = distanceInches / INCHES_PER_MILE;
    Serial.print("Total Passes: ");
    Serial.print(passCount);
    Serial.print(" | Distance: ");
    Serial.print(distanceMiles, 6);
    Serial.println(" miles");
    lastTime = currentTime;
  }

  delay(0); // run as fast as possible
}

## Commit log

2025-11-15 RW update
    [Fantabulous Snaget-Fulffy (4).stl]
2025-11-15 updated names
    [Hall-Effect Sensor System CAD.stl]
